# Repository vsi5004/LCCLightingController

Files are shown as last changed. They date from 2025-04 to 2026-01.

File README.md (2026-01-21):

# LCC Lighting Controller Board

The LCC Lighting Controller Board is an OpenLCB (LCC) node designed for controlling RGBW NeoPixel LED strips on model railroads. The system uses a controller/follower architecture where one controller board reads analog inputs (potentiometers) via an ADS1115 ADC and broadcasts RGBW values over the LCC bus, while multiple follower boards receive these events and synchronize their LED strips accordingly. You can also set up multiple follower boards with a different board as the controller, for example the [LCC Lighting Touchscreen Controller](https://github.com/vsi5004/LCC-Lighting-Touchscreen)

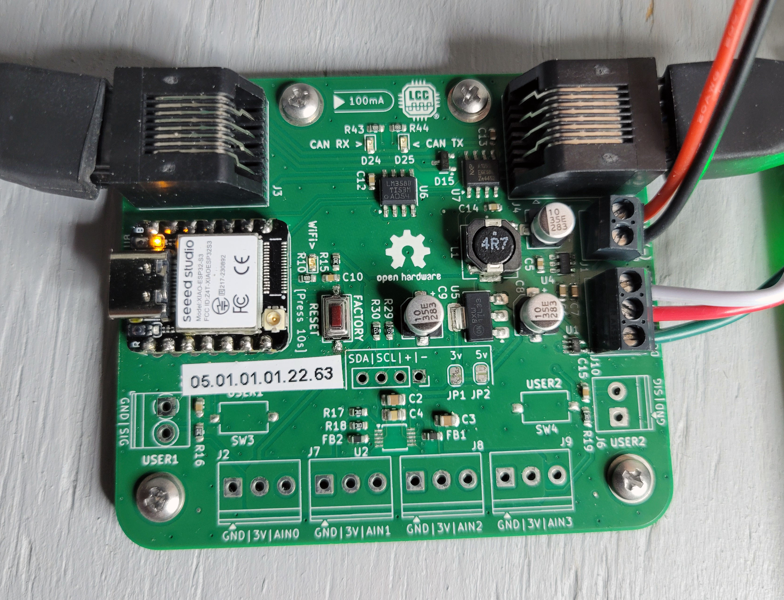
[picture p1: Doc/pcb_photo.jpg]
PCB Photo


The end result would be to have strings of LEDs as fully-customizable overhead lighting integrated into your LCC system. This opens up opportunities for custom scenes, rolling weather systems, and accurate sunsets/sunrises timed with a fast clock.

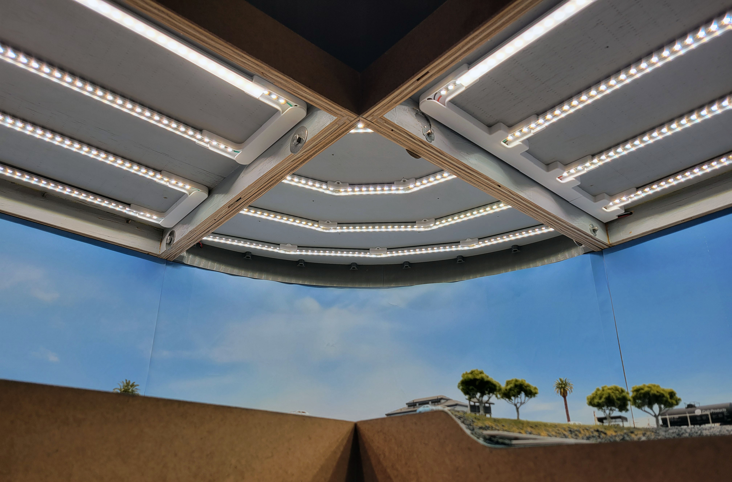
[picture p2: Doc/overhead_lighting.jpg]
Overhead Lighting Photo


## Features

- **RGBW Control**: Independent control of Red, Green, Blue, White channels plus overall brightness
- **Controller/Follower Architecture**: One controller can synchronize multiple follower boards
- **Automatic Detection**: Boards automatically detect if they have an ADS1115 ADC and configure as controller or follower
- **Wide LED Compatibility**: Uses the [NeoPixelBus library](https://github.com/Makuna/NeoPixelBus), supporting a wide range of addressable LED chips including WS2812, WS2812B, WS2811, SK6812 RGBW, WS2814 RGBWW. This is superior to teh previously utilized Adafruit neopixel library as it uses DMA to drive the LEDs, significantly reducing glitching and timing constraints on the ESP32 hardware
- **Configurable LED Count**: Support for strips up to 1000 LEDs
- **Startup Animation**: Configurable fade-in animation with adjustable delay for LCC bus settling
- **Periodic Sync**: Controller periodically broadcasts state to keep followers synchronized

>⚠️ **Version Constraint**: Currently limited to using Arduino ESP Core v3.2.1, as the NeoPixelBus library has a dependency on gpio_hal_iomux_func_sel which is not present in later versions. Will hopefully be resolved in [later releases](https://github.com/Makuna/NeoPixelBus/issues/895)

## Powering the LCC Lighting Controller Board

The LCC Lighting Controller Board must be powered from an external power supply (12V) on the J1 connector, do not attempt to use the OpenLCB (LCC) Bus power via the RJ45 connector as it will not supply enough power for any reasonably long string of LEDs.

### External Power Requirements

The external power supply should be rated for at least 12VDC 500mA to ensure sufficient current is available for the node to operate as intended. For longer LED strips, a higher current power supply may be required.

### Node Brownout Detection

If the ESP32 detects a brownout condition it will attempt to produce event `01.00.00.00.00.00.FF.F1` soon after startup. This delivery is not guaranteed.

## LCC Lighting Controller PCB

The LCC Lighting Controller Board PCB can be found under the PCB directory and is provided as both KiCad files and generated Gerber files.

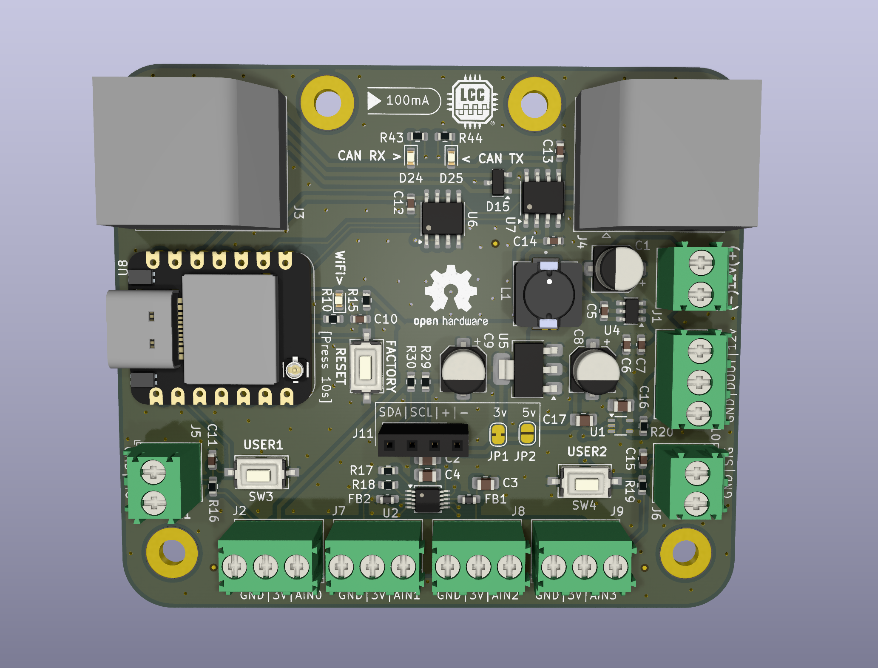
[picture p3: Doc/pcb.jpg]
PCB Render


### PCBWay Project

The LCC Lighting Controller PCB has been shared via PCBWay:

TODO: Add PCBWay Project link

### Mouser BOM

The LCC Lighting Controller Board components have been entered on Mouser for easy ordering via the following shared carts:

TODO: Add shared carts

Ordering in larger quantities can decrease the per-PCB cost considerably. In the case of resistors and capacitors it is recommended to order 100 of each as they are tiny and easily lost. Other parts can often be substituted as long as they have the same footprint and pinout.

## LCC Lighting Controller PCB Mount

You can find the Fusion 360 archive and 3MF files for a 3D-printable stand-off/spacer type mount in the Mount directory. This will allow for easy mounting of the Lighting Controller using self-tapping screws to the underside of any layout or a dedicated plywood electronics board. The Fusion 360 files can also be modified for your application, or used to create printable paper templates to transfer the mounting hole spacing of the board.

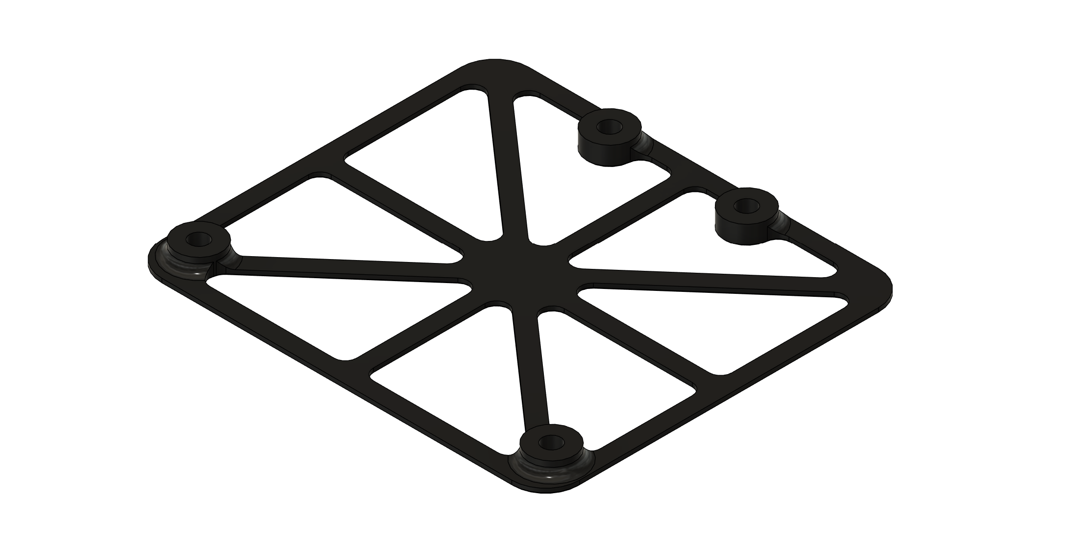
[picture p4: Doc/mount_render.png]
PCB Mount Render


## JMRI Configuration

The Lighting Controller must be plugged into an active LCC bus in order to be configured. The boards have been tested with a TCS CS-105 base station connected to a Raspberry Pi running JMRI.

Upon plugging in the Lighting Controller, you should see the entry for that device's address appear in the OpenLCB Network list:

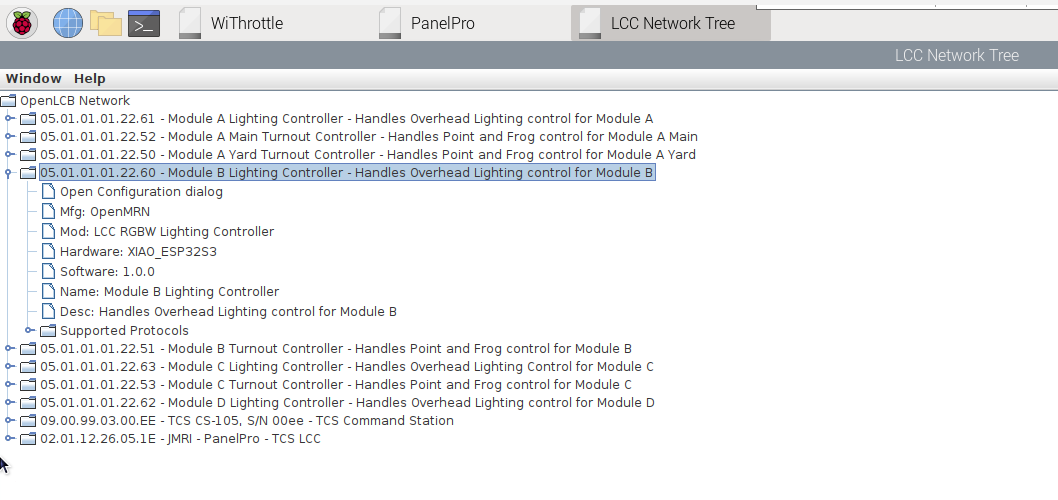
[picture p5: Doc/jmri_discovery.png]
JMRI Discovery


Clicking on the board in the OpenLCB Network list expands the entry to show an "Open Configuration Dialog" option. Clicking that opens a separate window where you can adjust:

- **Description**: User-friendly name for the light strip
- **Red/Green/Blue/White Channel Events**: Event ID bases for each color channel. Keep them at their default values for Controller boards. For Follower boards change them to match the events emitted by the Controller.
- **Brightness Event**: Event ID base for overall brightness control. Same guidelines apply here as the RGBW channel events.
- **Duration Event**: Event ID base for duration of the transition from current rgbw scene parameters to newly transmitted scene. Same guidelines apply her as with the RGBW channel events.
- **LED Count**: Number of LEDs in your NeoPixel strip (1-1000)
- **Sync Interval**: How often the controller broadcasts state to followers (0-60 seconds)
- **Startup Delay**: Delay before fade-in animation starts (0-30 seconds). This is helpful to allow the startup traffic on the LCC bus to die down before sending a block of lighting commands during the fade-on animation. Otherwise, receiving frequent external events on the Controller board can interrupt the neopixel commands, which may result in green glitching along the LED strip.

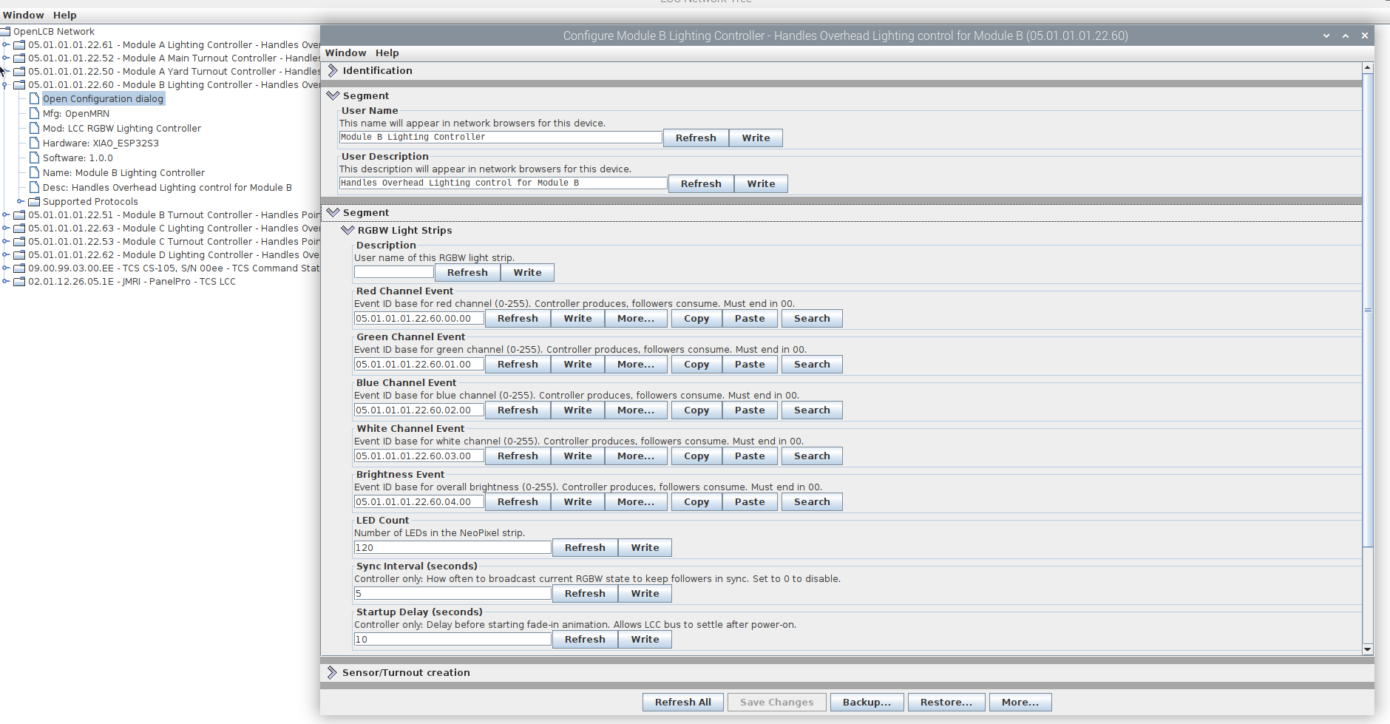
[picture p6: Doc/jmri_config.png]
JMRI Configuration


### Controller vs Follower Setup

- **Controller Board**: Install the ADS1115 ADC and connect potentiometers to control RGBW values. The board automatically detects the ADC and operates as a controller.
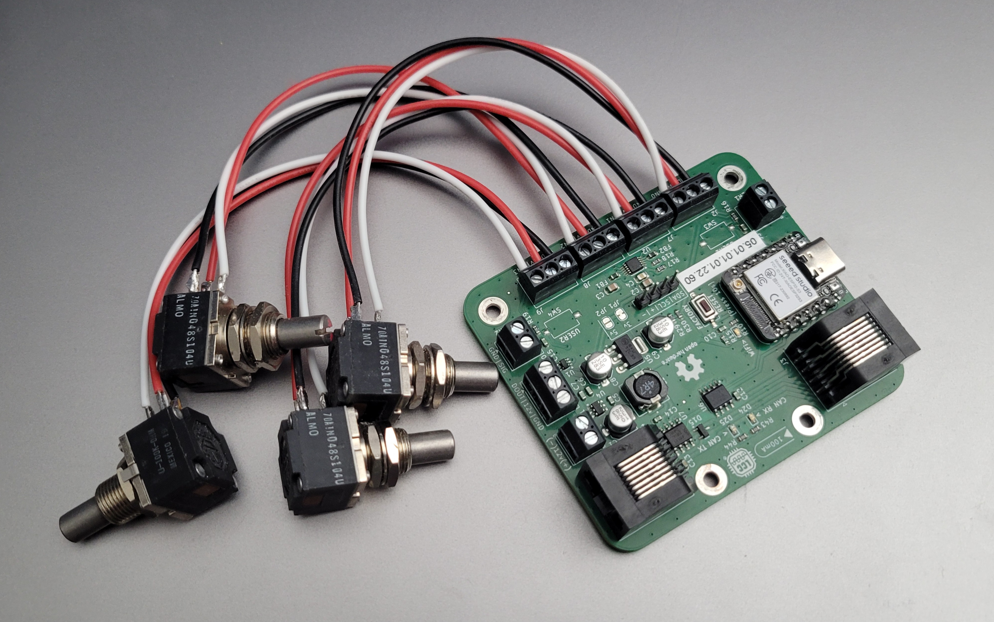
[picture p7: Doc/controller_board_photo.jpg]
Controller Board

- **Follower Board**: Do not install the ADS1115 ADC [U2 on the PCB]. The board will automatically operate as a follower, receiving RGBW events from the controller.
Follower Board

Ensure all boards sharing the same LED strip colors use matching Event ID bases for each channel.

## LCC Event Model

Events are transmitted to control RGBW lighting nodes using a 
**Duration-Triggered Fade Protocol**. The Controller (or touchscreen) sends target values and 
transition duration; Follower boards perform local high-fidelity fading at ~60fps.

### Event ID Format

```
05.01.01.01.9F.60.0X.VV
                  │  └── Value (0-255)
                  └───── Parameter
```

| Parameter | X | Description |
|---|---|---|
| Red | 0 | Red channel target intensity |
| Green | 1 | Green channel target intensity |
| Blue | 2 | Blue channel target intensity |
| White | 3 | White channel target intensity |
| Brightness | 4 | Master brightness target |
| Duration | 5 | Fade time in seconds (0=instant) |

### How It Works

1. **Controller sends 6 events**: R, G, B, W, Brightness, Duration
2. **Followers store** R, G, B, W, Brightness as pending values
3. **Duration event triggers** the fade from current to pending values
4. **Local interpolation** runs at ~60fps on Followers
5. **Minimal bus traffic**: Only 6 events per scene change

## Acknowledgements

This project borrows heavily from Mike Dunston's ESP32 OpenLCB IO Board for the PCB design:
https://github.com/atanisoft/Esp32OlcbIO

A lot of the code is based on Robert Heller's ESP32 LCC examples:
https://github.com/RobertPHeller/ESP32-LCC

Directly uses OpenMRNLite which is maintained by Balazs Racz and Stewart Baker:
https://github.com/openmrn/OpenMRNLite

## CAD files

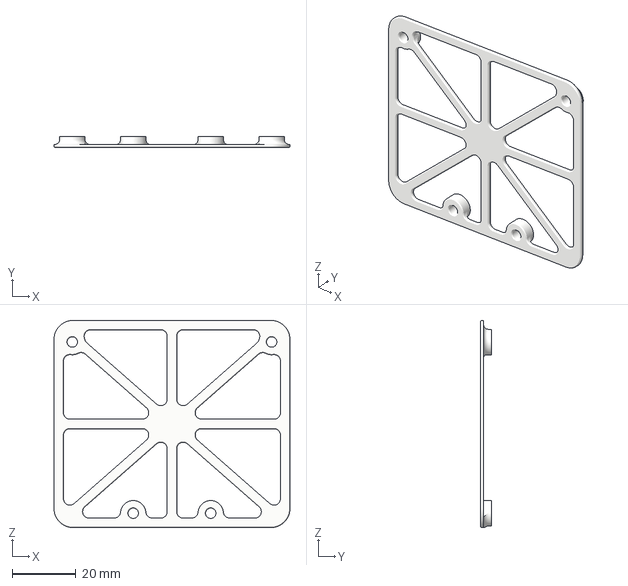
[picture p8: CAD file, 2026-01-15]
Mount/LCC Lighting Controller Mount v1.3mf
74.0 x 3.50 x 65.0 mm

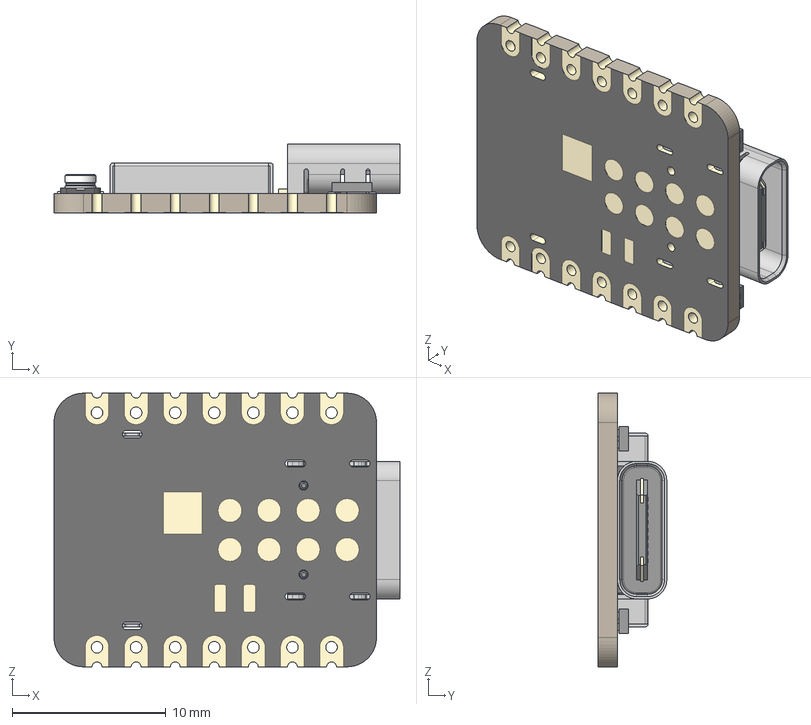
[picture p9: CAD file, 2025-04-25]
PCB/Components/XIAO-ESP32S3 v2.step
22.5 x 4.46 x 17.8 mm
BOSS-EXTRUDE14_8_
BOSS-EXTRUDE7_4_
BOSS-EXTRUDE7_3_
BOSS-EXTRUDE14_4_
BOSS-EXTRUDE14_2_
BOSS-EXTRUDE14_11_
BOSS-EXTRUDE7_7_
BOSS-EXTRUDE14_9_
BOSS-EXTRUDE14_3_
BOSS-EXTRUDE14_7_
MIRROR2
BOSS-EXTRUDE14_5_
BOSS-EXTRUDE14_12_
BOSS-EXTRUDE7_8_
BOSS-EXTRUDE7_1_
BOSS-EXTRUDE14_10_
BOSS-EXTRUDE7_9_
BOSS-EXTRUDE14_6_
BOSS-EXTRUDE14_1_
BOSS-EXTRUDE7_6_
BOSS-EXTRUDE7_2_
CUT-EXTRUDE5
BOSS-EXTRUDE7_5_
Shield
Pins x 2
U.FL-R-SMT-1_10_ v1

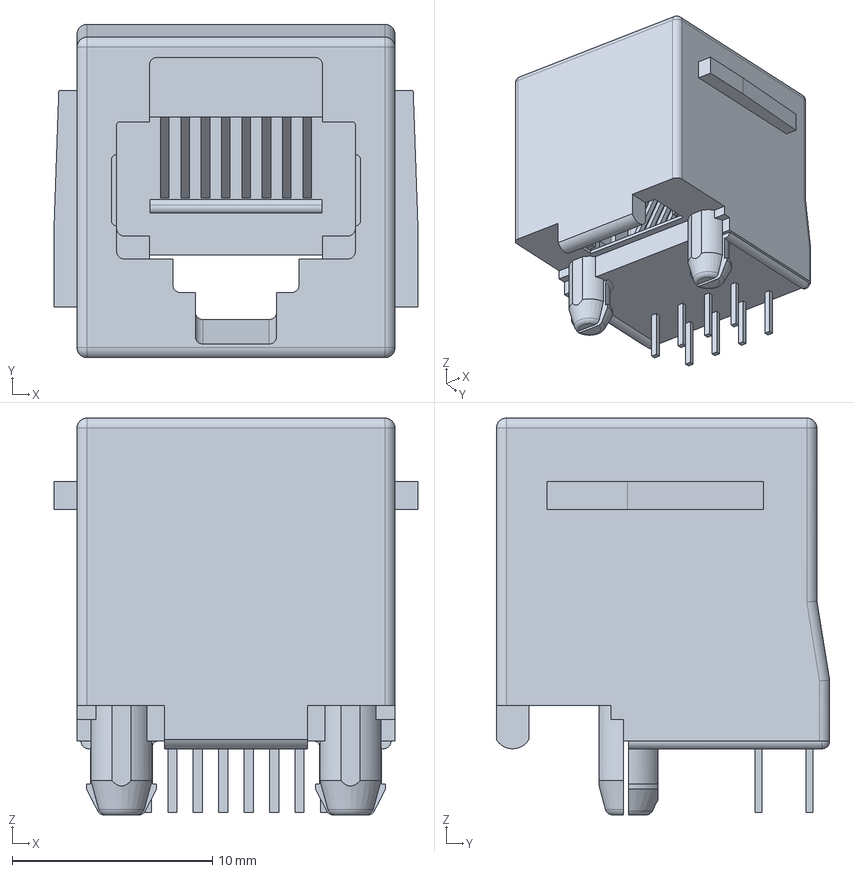
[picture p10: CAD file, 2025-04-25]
PCB/Components/c-5520259-4-c-3d.stp
18.2 x 16.6 x 19.8 mm

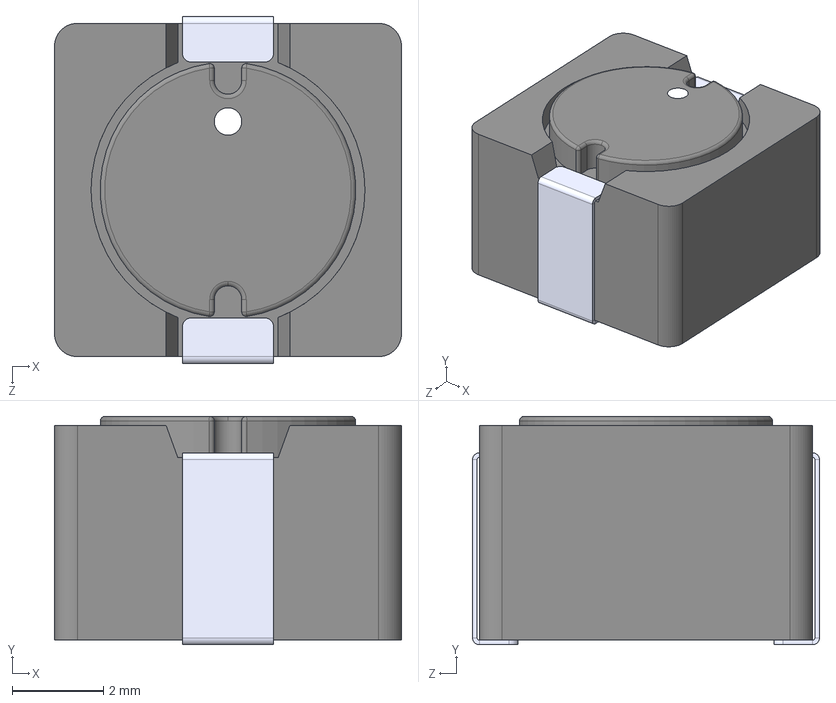
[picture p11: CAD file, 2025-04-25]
PCB/Components/B1047AS-221M=P3--3DModel-STEP-46669.STEP
7.60 x 5.00 x 7.60 mm

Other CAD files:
Mount/LCC Lighting Controller Mount v1.f3d

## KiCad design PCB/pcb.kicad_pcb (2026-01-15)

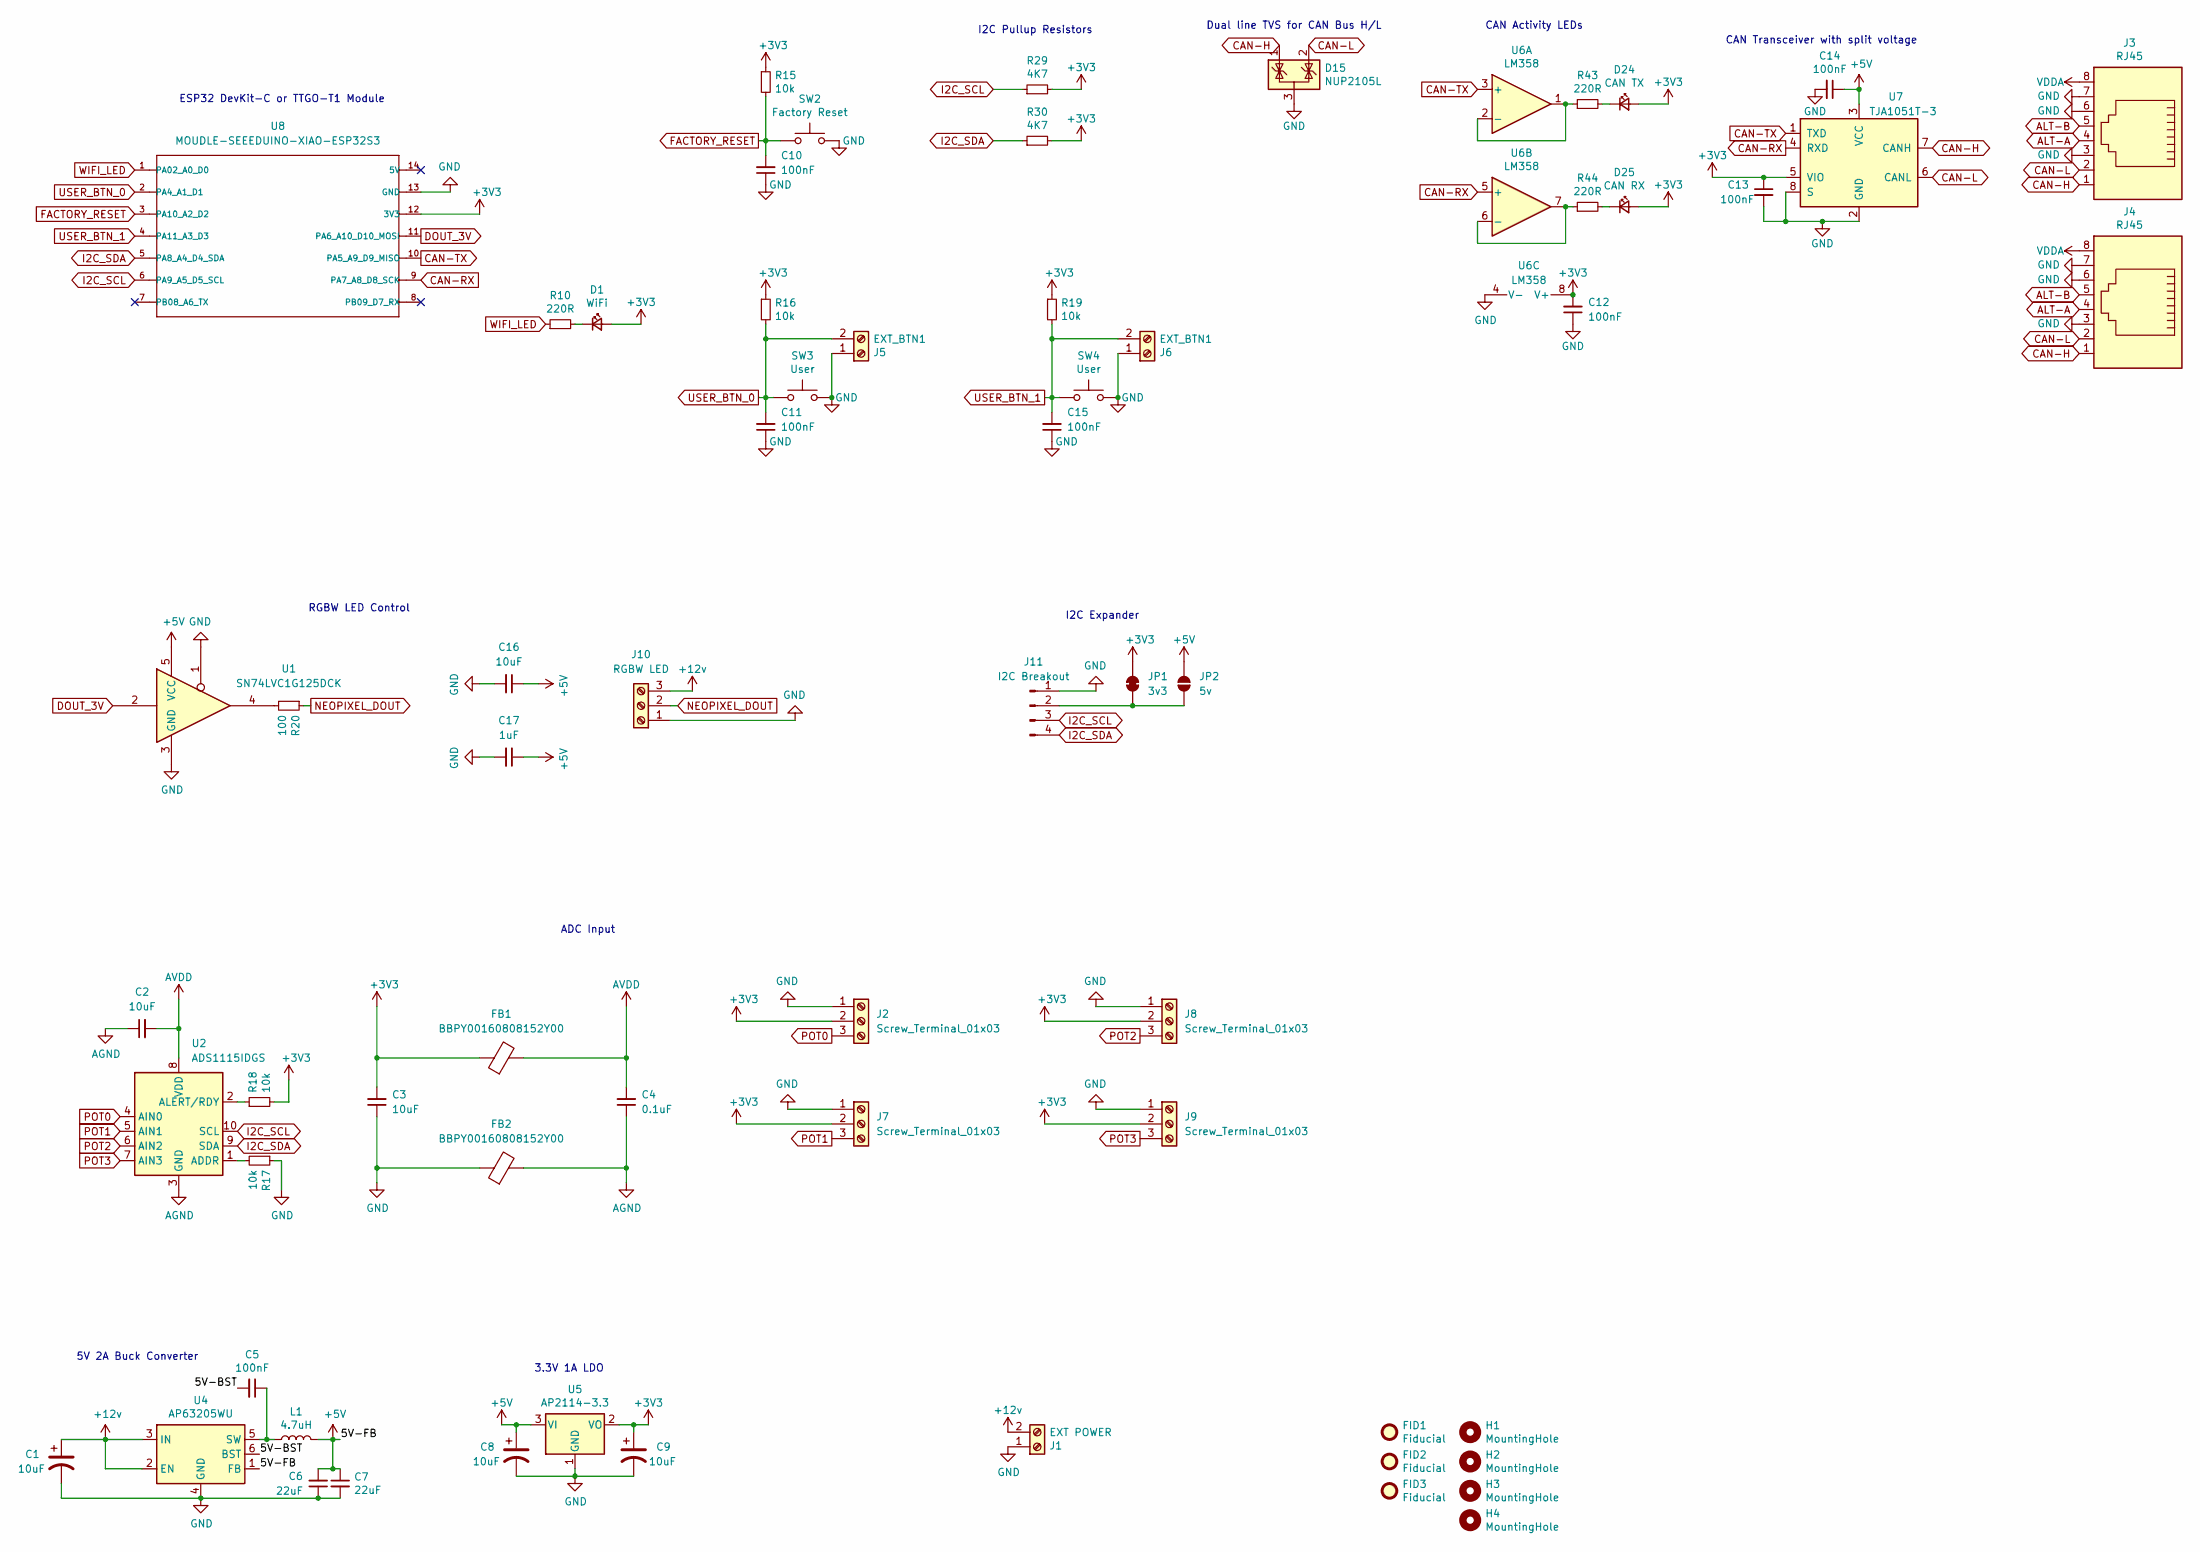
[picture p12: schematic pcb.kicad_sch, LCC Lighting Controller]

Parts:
C1, C8, C9: 10uF; CP_Elec_5x5.3; Mouser 710-865230542002
C2, C3, C16: 10uF; C_0805_2012Metric_Pad1.18x1.45mm_HandSolder
C4: 0.1uF; C_0805_2012Metric_Pad1.18x1.45mm_HandSolder
C5, C10, C11, C12, C13, C14, C15: 100nF; C_0603_1608Metric; Mouser 710-885012206020
C6, C7: 22uF; C_0603_1608Metric; Mouser 603-CC0603MRX6S5B226
C17: 1uF; C_0805_2012Metric_Pad1.18x1.45mm_HandSolder
D1: WiFi; LED_0603_1608Metric; Mouser 710-150060VS55040
D15: NUP2105L; SOT-23; Mouser 863-SZNUP2105LT3G
D24: CAN TX; LED_0603_1608Metric; Mouser 710-150060YS75000
D25: CAN RX; LED_0603_1608Metric; Mouser 710-150060AS75000
FB1, FB2: BBPY00160808152Y00; L_0603_1608Metric_Pad1.05x0.95mm_HandSolder
FID1, FID2, FID3: Fiducial; Fiducial_0.5mm_Mask1mm
H1, H2, H3, H4: MountingHole; MountingHole_3.2mm_M3_Pad
J1: EXT POWER; TerminalBlock_Phoenix_PT-1,5-2-3.5-H_1x02_P3.50mm_Horizontal; Mouser 651-1984617
J2, J7, J8, J9: Screw_Terminal_01x03; TerminalBlock_Phoenix_PT-1,5-3-3.5-H_1x03_P3.50mm_Horizontal
J3, J4: RJ45; RJ45_TE_CONNECTIVITY_5555164-1_Horizontal-Low_Profile; Mouser 571-5569284-1 or 534-949 or 493-HCJV1-8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
J5, J6: EXT_BTN1; TerminalBlock_Phoenix_PT-1,5-2-3.5-H_1x02_P3.50mm_Horizontal; Mouser 651-1984617
J10: RGBW LED; TerminalBlock_Phoenix_PT-1,5-3-3.5-H_1x03_P3.50mm_Horizontal
J11: I2C Breakout; PinSocket_1x04_P2.54mm_Vertical
JP1: 3v3; SolderJumper-2_P1.3mm_Bridged_RoundedPad1.0x1.5mm
JP2: 5v; SolderJumper-2_P1.3mm_Open_RoundedPad1.0x1.5mm
L1: 4.7uH; IND_B1047AS-4R7N=P3; Mouser 81-B1047AS-4R7NP3
R10, R43, R44: 220R; R_0603_1608Metric; Mouser 603-AC0603JR-07160RL
R15, R16, R17, R18, R19: 10k; R_0603_1608Metric; Mouser 71-CRCW06030000Z0EAC
R20: 100; R_0603_1608Metric; Mouser 71-CRCW06030000Z0EAC
R29, R30: 4K7; R_0603_1608Metric; Mouser 603-AC0603JR-07160RL
SW2: Factory Reset; SW_Tactile_SPST_NO_Straight_CK_PTS636Sx25SMTRLFS; Mouser 667-EVQ-PE104K
SW3, SW4: User; SW_Tactile_SPST_NO_Straight_CK_PTS636Sx25SMTRLFS; Mouser 667-EVQ-PE104K
U1: SN74LVC1G125DCK; Texas_R-PDSO-G5_DCK-5
U2: ADS1115IDGS; TSSOP-10_3x3mm_P0.5mm
U4: AP63205WU; TSOT-23-6; Mouser 621-AP63205WU-7
U5: AP2114-3.3; SOT-223-3_TabPin2; Mouser 621-AP2114H-3.3TRG1
U6: LM358; SOIC-8_3.9x4.9mm_P1.27mm; Mouser 595-LM358BIDR
U7: TJA1051T-3; SOIC-8_3.9x4.9mm_P1.27mm; Mouser 726-IFX1050GVIOXUMA1
U8: MOUDLE-SEEEDUINO-XIAO-ESP32S3; MCU_Seeed_ESP32C3_TH

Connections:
+3V3: C3.2, C9.1, C12.2, C13.1, D1.2 (A), D24.2 (A), D25.2 (A), FB1.1, J2.2, J7.2, J8.2, J9.2, JP1.2 (B), R15.1, R16.1, R18.2, R19.1, R29.2, R30.2, U5.2 (VO), U6.8 (V+), U7.5 (VIO), U8.12 (3V3)
+5V: C6.2, C7.1, C8.1, C14.1, C16.1, C17.1, JP2.2 (B), L1.2, U1.5 (VCC), U4.1 (FB), U5.3 (VI), U7.3 (VCC)
+12v: C1.1, J1.2, J10.3, U4.2 (EN), U4.3 (IN)
/5V-BST: C5.2, U4.6 (BST)
AGND: C2.1, C4.1, FB2.2, U2.3 (GND)
ALT-A: J3.4, J4.4
ALT-B: J3.5, J4.5
AVDD: C2.2, C4.2, FB1.2, U2.8 (VDD)
CAN-H: D15.1 (K), J3.1, J4.1, U7.7 (CANH)
CAN-L: D15.2 (K), J3.2, J4.2, U7.6 (CANL)
CAN-RX: U6.5 (+), U7.4 (RXD), U8.9 (PA7_A8_D8_SCK)
CAN-TX: U6.3 (+), U7.1 (TXD), U8.10 (PA5_A9_D9_MISO)
DOUT_3V: U1.2, U8.11 (PA6_A10_D10_MOSI)
FACTORY_RESET: C10.2, R15.2, SW2.1, U8.3 (PA10_A2_D2)
GND: C1.2, C3.1, C6.1, C7.2, C8.2, C9.2, C10.1, C11.1, C12.1, C13.2, C14.2, C15.1, C16.2, C17.2, D15.3 (A), FB2.1, J1.1, J2.1, J3.3, J3.6, J3.7, J4.3, J4.6, J4.7, J5.1, J6.1, J7.1, J8.1, J9.1, J10.1, J11.1, R17.1, SW2.2, SW3.2, SW4.2, U1.1, U1.3 (GND), U4.4 (GND), U5.1 (GND), U6.4 (V-), U7.2 (GND), U7.8 (S), U8.13 (GND)
I2C_SCL: J11.3, R29.1, U2.10 (SCL), U8.6 (PA9_A5_D5_SCL)
I2C_SDA: J11.4, R30.1, U2.9 (SDA), U8.5 (PA8_A4_D4_SDA)
NEOPIXEL_DOUT: J10.2, R20.1
unnamed: D1.1 (K), R10.2
unnamed: D24.1 (K), R43.2
unnamed: D25.1 (K), R44.2
unnamed: J11.2, JP1.1 (A), JP2.1 (A)
unnamed: R20.2, U1.4
unnamed: R17.2, U2.1 (ADDR)
unnamed: R18.1, U2.2 (ALERT/RDY)
unnamed: C5.1, L1.1, U4.5 (SW)
unnamed: R43.1, U6.1, U6.2 (-)
unnamed: R44.1, U6.6 (-), U6.7
POT0: J2.3, U2.4 (AIN0)
POT1: J7.3, U2.5 (AIN1)
POT2: J8.3, U2.6 (AIN2)
POT3: J9.3, U2.7 (AIN3)
USER_BTN_0: C11.2, J5.2, R16.2, SW3.1, U8.2 (PA4_A1_D1)
USER_BTN_1: C15.2, J6.2, R19.2, SW4.1, U8.4 (PA11_A3_D3)
VDDA: J3.8, J4.8
WIFI_LED: R10.1, U8.1 (PA02_A0_D0)

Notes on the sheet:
I2C Pullup Resistors
5V 2A Buck Converter
3.3V 1A LDO
ESP32 DevKit-C or TTGO-T1 Module
CAN Transceiver with split voltage
RGBW LED Control
I2C Expander
ADC Input
CAN Activity LEDs
Dual line TVS for CAN Bus H/L

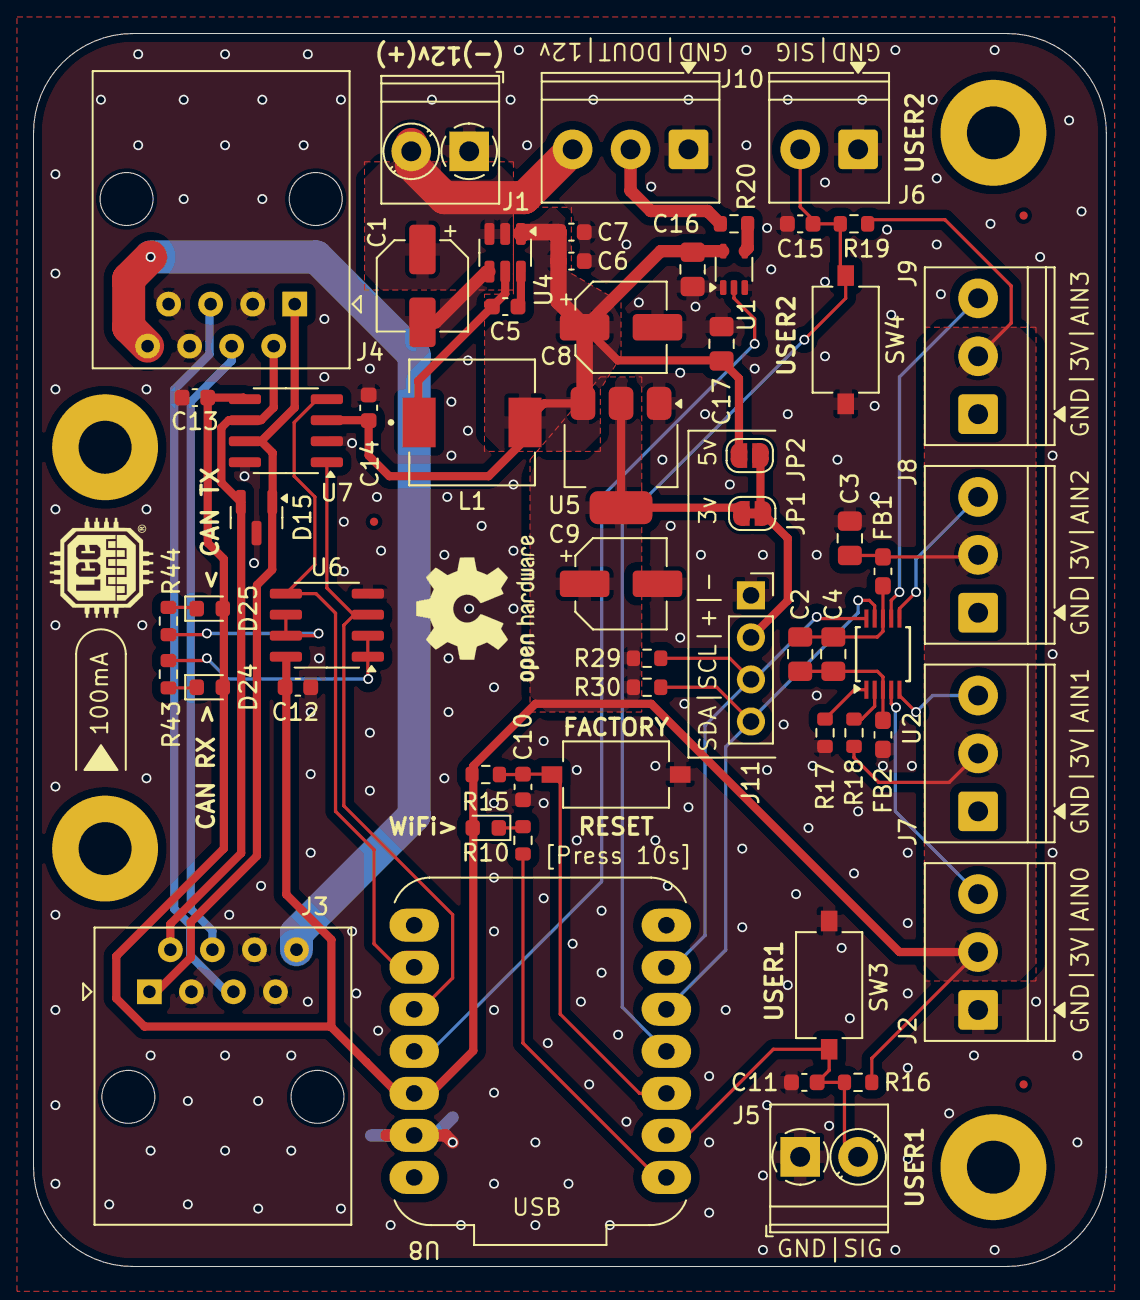
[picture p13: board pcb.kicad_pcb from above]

Board: 2 copper layers, 64.8 x 74.5 mm, 65 parts (0 on the bottom side), 36 nets.

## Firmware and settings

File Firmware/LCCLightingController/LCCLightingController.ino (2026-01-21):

#include <Arduino.h>
#include <Ticker.h>
#include <SPIFFS.h>
#include <OpenMRNLite.h>
#include <Wire.h>
#include <Adafruit_NeoPixel.h>
#include <ADS1115_WE.h>

#include "config.h"
#include "NODEID.h"
#include "RGBWStrip.h"

static constexpr openlcb::ConfigDef cfg(0);
static constexpr uint8_t NUM_RGBW_STRIPS = openlcb::NUM_RGBW_STRIPS;

namespace openlcb {
  // Define SNIP_STATIC_DATA (declared in config.h)
  const SimpleNodeStaticValues SNIP_STATIC_DATA = {
      4,
      "OpenMRN",
      "LCC RGBW Lighting Controller",
      ARDUINO_VARIANT,
      "1.0.0"
  };

  const char CDI_FILENAME[] = "/spiffs/cdi.xml";
  extern const char CDI_DATA[] = "";
  extern const char *const CONFIG_FILENAME = "/spiffs/openlcb_config";
  extern const size_t CONFIG_FILE_SIZE = cfg.seg().size() + cfg.seg().offset();
  extern const char *const SNIP_DYNAMIC_FILENAME = CONFIG_FILENAME;
}

ADS1115_WE adc = ADS1115_WE();
Esp32HardwareTwai twai(D8, D9);
OpenMRN openmrn(NODE_ID);

openlcb::RGBWStrip *rgbwStrip = nullptr;
bool isController = false;

// Track when to start the fade animation
static unsigned long initCompleteTime = 0;
static bool fadeStarted = false;


void setup() {
  Serial.begin(115200);
  Wire.begin();

  delay(100);

  Serial.println("\n\n=== LCC RGBW Lighting Controller ===");
  Serial.printf("Node ID: 0x%012llX\n", NODE_ID);

  // Initialize SPIFFS
  if (!SPIFFS.begin()) {
    Serial.println("SPIFFS failed to mount, formatting...");
    if (!SPIFFS.begin(true)) {
      Serial.println("SPIFFS mount failed. Halting.");
      while (1);
    }
  }

  openmrn.create_config_descriptor_xml(cfg, openlcb::CDI_FILENAME);
  
  // Create config file if needed and check if factory reset is required
  Serial.printf("Checking config file (expecting version 0x%04X)...\n", openlcb::CANONICAL_VERSION);
  
  // Read current version before calling create_config_file_if_needed
  int fd_check = ::open(openlcb::CONFIG_FILENAME, O_RDONLY);
  uint16_t current_version = 0;
  bool needsFactoryReset = false;
  if (fd_check >= 0) {
    current_version = cfg.seg().internal_config().version().read(fd_check);
    ::close(fd_check);
    Serial.printf("Current stored version: 0x%04X\n", current_version);
    needsFactoryReset = (current_version != openlcb::CANONICAL_VERSION);
  } else {
    Serial.println("Config file does not exist yet");
    needsFactoryReset = true;
  }
  
  int config_fd = openmrn.stack()->create_config_file_if_needed(
    cfg.seg().internal_config(),
    openlcb::CANONICAL_VERSION,
    openlcb::CONFIG_FILE_SIZE);
  Serial.printf("Config check complete, fd=%d\n", config_fd);

  // Initialize ADS1115 (controller only, but harmless if not populated)
  if (!adc.init()) {
    isController = false;
    Serial.println("ADS1115 not detected - will run as FOLLOWER");
  } else {
    isController = true;
    adc.setVoltageRange_mV(ADS1115_RANGE_4096);
    adc.setCompareChannels(ADS1115_COMP_0_GND);
    adc.setConvRate(ADS1115_250_SPS);
    adc.setMeasureMode(ADS1115_CONTINUOUS);
    Serial.println("ADS1115 detected - can run as CONTROLLER");
  }

  // Create RGBW strip controller and initialize if needed
  rgbwStrip = new openlcb::RGBWStrip(
    openmrn.stack()->node(),
    cfg.seg().rgbw_strips().entry(0),
    &adc
  );
  
  // Only reset RGBW config when config file is new or version changed
  if (needsFactoryReset) {
    Serial.println("Initializing RGBW config defaults...");
    rgbwStrip->factory_reset(config_fd);
    Serial.println("RGBW config initialized");
  } else {
    Serial.println("Config file valid, preserving user settings");
  };

  // Initialize OpenMRN stack
  openmrn.begin();
  openmrn.start_executor_thread();
  
  // Initialize CAN/TWAI
  twai.hw_init();
  openmrn.add_can_port_select("/dev/twai/twai0");

  pinMode(LED_BUILTIN, OUTPUT);
  digitalWrite(LED_BUILTIN, LOW);

  Serial.println("=== Initialization Complete ===\n");
}

void loop() {
  openmrn.loop();

  // Record init complete time on first loop iteration
  if (initCompleteTime == 0) {
    initCompleteTime = millis();
  }

  // Follower: Poll fade animation (handles local high-fidelity fade)
  if (!isController) {
    rgbwStrip->poll_fade();
  }

  // Controller: Start fade animation after configured delay (allows LCC bus to settle)
  if (isController && !fadeStarted) {
    unsigned long delayMs = rgbwStrip->startup_delay_sec() * 1000UL;
    if (millis() - initCompleteTime >= delayMs) {
      Serial.printf("Starting fade-in animation (after %d sec delay)...\n", rgbwStrip->startup_delay_sec());
      rgbwStrip->run_startup_animation();
      fadeStarted = true;
    }
  }

  // Controller: Poll ADC inputs every 10ms (only if this device is a controller)
  if (isController) {
    static unsigned long lastPoll = 0;
    if (millis() - lastPoll >= 10) {
      rgbwStrip->poll_adc_inputs();
      lastPoll = millis();
    }
  }

  // Heartbeat LED
  static unsigned long lastBlink = 0;
  if (millis() - lastBlink >= 1000) {
    digitalWrite(LED_BUILTIN, !digitalRead(LED_BUILTIN));
    lastBlink = millis();
  }
}

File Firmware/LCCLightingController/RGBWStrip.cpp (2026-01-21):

#include "RGBWStrip.h"
#include "config.h"

namespace openlcb {

// ============================================================================
// RGBWStrip Implementation
// ============================================================================

RGBWStrip::RGBWStrip(Node *node, const RGBWConfig &cfg, ADS1115_WE *adc)
    : node_(node), cfg_(cfg), adc_(adc),
      strip_(nullptr), isController_(false),
      currentR_(0), currentG_(0), currentB_(0), currentW_(0), currentBrightness_(255),
      pendingR_(0), pendingG_(0), pendingB_(0), pendingW_(0), pendingBrightness_(255),
      fadeInProgress_(false), fadeStartTime_(0), fadeDurationMs_(0),
      fadeStartR_(0), fadeStartG_(0), fadeStartB_(0), fadeStartW_(0), fadeStartBrightness_(255),
      fadeTargetR_(0), fadeTargetG_(0), fadeTargetB_(0), fadeTargetW_(0), fadeTargetBrightness_(255),
      lastSentR_(0), lastSentG_(0), lastSentB_(0), lastSentW_(0), lastSentBrightness_(255),
      adcChannelIndex_(0), lastEventSendTime_(0), startupAnimationComplete_(false),
      lastShowTime_(0), stripDirty_(false),
      animState_(ANIM_IDLE), animTargetR_(0), animTargetG_(0), animTargetB_(0), animTargetW_(0),
      animBrightness_(0), animLastUpdate_(0), animStep_(0),
      syncIntervalSec_(3), lastSyncTime_(0), syncStep_(-1), lastSyncStepTime_(0),
      startupDelaySec_(5) {
    for (int i = 0; i < 6; i++) {
        eventIds_[i] = 0;
        eventHandlers_[i] = nullptr;
    }
}

RGBWStrip::~RGBWStrip() {
    if (strip_) delete strip_;
    for (int i = 0; i < 6; i++) {
        if (eventHandlers_[i]) delete eventHandlers_[i];
    }
}

ConfigUpdateListener::UpdateAction RGBWStrip::apply_configuration(int fd, bool initial_load, 
                                            BarrierNotifiable *done) {
    AutoNotify n(done);

    // Default values to use if config cannot be read
    uint16_t ledCount = DEFAULT_LED_COUNT;
    bool useDefaults = false;

    // Check if file descriptor is valid
    if (fd < 0) {
        Serial.printf("WARNING: Invalid file descriptor (fd=%d), using default configuration\n", fd);
        useDefaults = true;
    }

    if (!useDefaults) {
        ledCount = cfg_.led_count().read(fd);
        // Sanity check - use default if invalid
        if (ledCount == 0 || ledCount == 0xFFFF || ledCount > 1000) {
            ledCount = DEFAULT_LED_COUNT;
            Serial.printf("Invalid LED count, using default: %d\n", ledCount);
        }
    }
    
    // Auto-detect controller mode based on ADC presence
    if (adc_ && !adc_->isDisconnected()) {
        isController_ = true;
        Serial.println("Auto-detect: ADS1115 detected - configured as CONTROLLER");
    } else {
        isController_ = false;
        Serial.println("Auto-detect: No ADS1115 - configured as FOLLOWER");
    }
    
    // Read event IDs for each channel (use defaults if fd invalid)
    if (!useDefaults) {
        eventIds_[0] = cfg_.red_event().read(fd);
        eventIds_[1] = cfg_.green_event().read(fd);
        eventIds_[2] = cfg_.blue_event().read(fd);
        eventIds_[3] = cfg_.white_event().read(fd);
        eventIds_[4] = cfg_.brightness_event().read(fd);
        eventIds_[5] = cfg_.duration_event().read(fd);
    } else {
        // Use default event IDs from config.h
        eventIds_[0] = RGBW_EVENT_INIT[0];
        eventIds_[1] = RGBW_EVENT_INIT[1];
        eventIds_[2] = RGBW_EVENT_INIT[2];
        eventIds_[3] = RGBW_EVENT_INIT[3];
        eventIds_[4] = RGBW_EVENT_INIT[4];
        eventIds_[5] = RGBW_EVENT_INIT[5];
    }
    
    Serial.printf("Event IDs - R:0x%016llX G:0x%016llX B:0x%016llX W:0x%016llX Br:0x%016llX Dur:0x%016llX\n",
                 eventIds_[0], eventIds_[1], eventIds_[2], eventIds_[3], eventIds_[4], eventIds_[5]);

    // Reinitialize NeoPixel strip if parameters changed
    if (!strip_ || strip_->numPixels() != ledCount) {
        if (strip_) delete strip_;
        strip_ = new Adafruit_NeoPixel(ledCount, NEOPIXEL_PIN, NEO_WRGB + NEO_KHZ800);
        strip_->begin();
        //strip_->setBrightness(0);  // Start with brightness 0 for clean fade-in
        //strip_->fill(strip_->Color(0, 0, 0, 0));
        //strip_->show();
        Serial.printf("NeoPixel initialized: %d LEDs on pin %d\n", ledCount, NEOPIXEL_PIN);
    }

    // Register event handlers only for followers (controller only sends, doesn't receive)
    if (!isController_) {
        for (int i = 0; i < 6; i++) {
            if (!eventHandlers_[i]) {
                eventHandlers_[i] = new RGBWEventHandler(this, i);
            }
        }
        Serial.println("Event handlers registered for all 6 channels (RGBW+Br+Dur)");
    } else {
        // Controller: read sync interval and startup delay config
        if (!useDefaults) {
            syncIntervalSec_ = cfg_.sync_interval().read(fd);
            if (syncIntervalSec_ > 60) syncIntervalSec_ = 3; // Sanity check
            startupDelaySec_ = cfg_.startup_delay().read(fd);
            if (startupDelaySec_ > 30) startupDelaySec_ = 5; // Sanity check
        }
        // If useDefaults, keep constructor default values (syncIntervalSec_=3, startupDelaySec_=5)
        Serial.printf("Controller sync interval: %d seconds\n", syncIntervalSec_);
        Serial.printf("Controller startup delay: %d seconds\n", startupDelaySec_);
        Serial.println("Controller mode - event handlers not registered (send only)");
    }

    if (isController_) {
        Serial.println("Running as CONTROLLER (HMI device)");
    } else {
        Serial.println("Running as FOLLOWER");
    }

    return UPDATED;
}

void RGBWStrip::factory_reset(int fd) {
    cfg_.description().write(fd, "");
    CDI_FACTORY_RESET(cfg_.led_count);
    cfg_.red_event().write(fd, RGBW_EVENT_INIT[0]);
    cfg_.green_event().write(fd, RGBW_EVENT_INIT[1]);
    cfg_.blue_event().write(fd, RGBW_EVENT_INIT[2]);
    cfg_.white_event().write(fd, RGBW_EVENT_INIT[3]);
    cfg_.brightness_event().write(fd, RGBW_EVENT_INIT[4]);
    cfg_.duration_event().write(fd, RGBW_EVENT_INIT[5]);
}

void RGBWStrip::run_startup_animation() {
    if (!isController_ || !strip_) return;
    
    // Start the non-blocking animation state machine
    animState_ = ANIM_READ_ADC;
    animStep_ = 0;
    animLastUpdate_ = millis();
    Serial.println("Starting startup animation...");
}
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

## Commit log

2025-04-25 Add PCB files
    [B1047AS-221M=P3--3DModel-STEP-46669.STEP, XIAO-ESP32S3 v2.step, c-5520259-4-c-3d.stp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]
2026-01-13 Initial firmware implementation (#1)
    * Initial commit bringing FW over from LCC Turnout Controller
    * FW works on coordinating device but does not support LCC communication
    * Update to send/receive single message per lighting parameter, fix event ID bug
    * Add startup animation, fix bugs with event mask filter
    * Update NODE_ID, add sync interval configuration, and implement periodic sync for RGBW controller
    * Add startup delay configuration and implement fade-in animation for RGBW controller
    * PR Changes
    [LCCLightingController.ino, RGBWStrip.cpp]
2026-01-15 Update PCB files with latest rev, export fabrication outputs, update README and add documentation photos
    [LCC Lighting Controller Mount v1.3mf, LCC Lighting Controller Mount v1.f3d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]
2026-01-21 Update to use new transition duration protocol, add factory reset button functionality, update neopixel driver to use DMA library
